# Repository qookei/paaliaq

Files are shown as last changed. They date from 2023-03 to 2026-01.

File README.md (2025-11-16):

# Paaliaq

Paaliaq is a WDC W65C816-based single board computer and the
accompanying software, with support for e.g. modern memory management
features, and kernel/user priviledge separation.

The project is currently in early stages of development, with most of
the current work focusing on the chipset implemntation. Proper
documentation TBD.

## Specifications

Using the iCESugar-pro SoM with the following specifications as the
base FPGA board:

 - Lattice ECP5 LFE5U-25F FPGA
 - 32MiB of SDR SDRAM
 - 32MiB SPI flash (holding the bitstream, with free space after it)
 - SD card slot
 - RGB led

The project is currently using a soft-core 65C816 implementation, with
future plans for a custom PCB holding an actual 65C816 chip, a SODIMM
slot for the FPGA SoM and breaking out various IO interfaces (HDMI,
UARTs, GPIO, etc).

## How?

Supporting the features mentioned above is made possible due to the
inclusion of the `ABORTB` signal on the 65C816 CPU, which allows the
currently executing instruction to be aborted, preventing register
changes and memory reads/writes, and allowing the instruction to
potentially be retried after returning from the handler.

To facilitate this, the FPGA contains not only the memory controller
and various peripherals, but also a page-based memory management unit,
which performs address translation and permission checks, signaling
errors to the CPU via the aforementioned abort signal.

## Directory structure and building

Each of the following subdirectories has instructions on how to build
it's contents:

 - `rtl` - The source code for the FPGA implementation of the chipset.
 - `toolchain` - The source code for the toolchain (assembler, etc).

## License

This project is licensed under the GNU General Public License, either
version 3, or (at your opinion) any later version.

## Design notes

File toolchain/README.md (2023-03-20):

# Paaliaq toolchain

This directory contains the sources for the toolchain designed for use
with the system.

The toolchain is written in Scheme and uses [GNU Guile](https://www.gnu.org/software/guile/)
as the Scheme implementation.

In contrast to regular assemblers, this assembler can be thought of more
as a set of functions and libraries that provide an assembly-looking DSL,
with the full power of Scheme for implementing assembler macros and such.

The main component of the assembler is the `paaliaq-as` script, which
contains the core functionality (translating instruction mnemonics into
bytes and such), and handles processing the command-line arguments and
loading the user-specified sources.

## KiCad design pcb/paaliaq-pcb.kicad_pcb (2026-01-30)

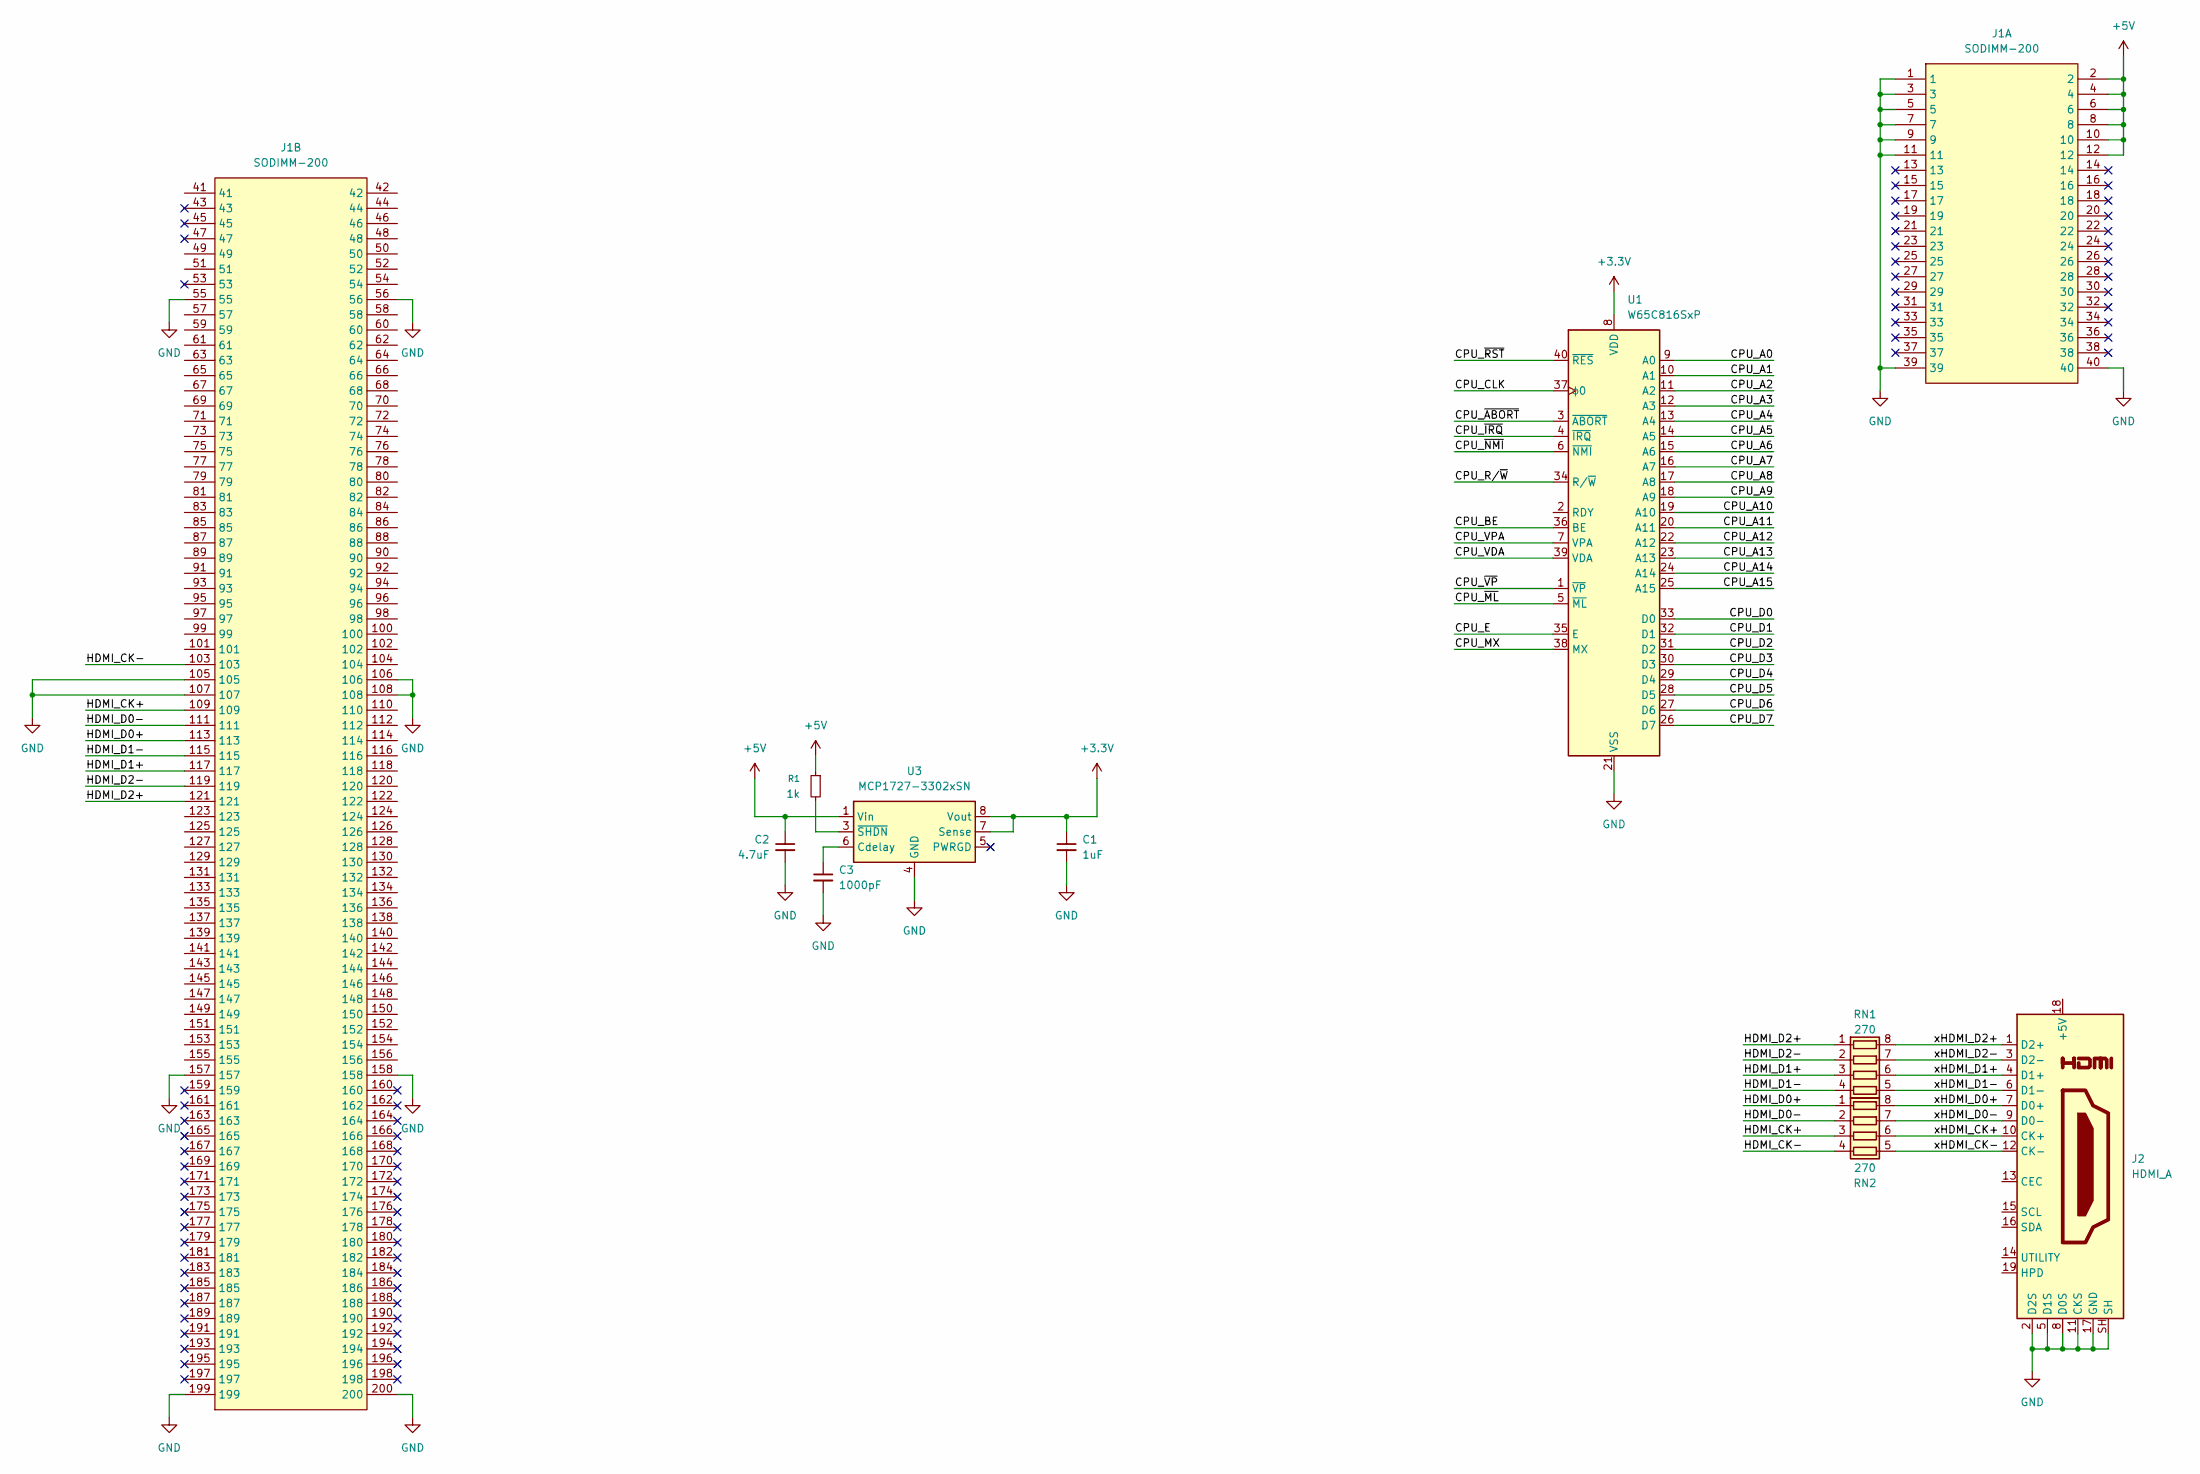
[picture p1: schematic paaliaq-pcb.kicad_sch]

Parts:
C1: 1uF; C_0805_2012Metric_Pad1.18x1.45mm_HandSolder
C2: 4.7uF; C_0805_2012Metric_Pad1.18x1.45mm_HandSolder
C3: 1000pF; C_0805_2012Metric_Pad1.18x1.45mm_HandSolder
J1: SODIMM-200; TE_1473005-1_2x100_P0.6mm_Horizontal
J2: HDMI_A; HDMI_A_Amphenol_10029449-x01xLF_Horizontal
R1: 1k; R_0805_2012Metric_Pad1.20x1.40mm_HandSolder
RN1, RN2: 270; R_Array_Convex_4x1206
U1: W65C816SxP; DIP-40_W15.24mm_Socket
U3: MCP1727-3302xSN; SOIC-8_3.9x4.9mm_P1.27mm

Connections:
+3.3V: C1.1, U1.8 (VDD), U3.7 (Sense), U3.8 (Vout)
+5V: C2.1, J1.2, J1.4, J1.6, J1.8, J1.10, J1.12, R1.1, U3.1 (Vin), U3.2 (Vin)
/CPU_A0: U1.9 (A0)
/CPU_A1: U1.10 (A1)
/CPU_A2: U1.11 (A2)
/CPU_A3: U1.12 (A3)
/CPU_A4: U1.13 (A4)
/CPU_A5: U1.14 (A5)
/CPU_A6: U1.15 (A6)
/CPU_A7: U1.16 (A7)
/CPU_A8: U1.17 (A8)
/CPU_A9: U1.18 (A9)
/CPU_A10: U1.19 (A10)
/CPU_A11: U1.20 (A11)
/CPU_A12: U1.22 (A12)
/CPU_A13: U1.23 (A13)
/CPU_A14: U1.24 (A14)
/CPU_A15: U1.25 (A15)
/CPU_BE: U1.36 (BE)
/CPU_CLK: U1.37 (ϕ0)
/CPU_D0: U1.33 (D0)
/CPU_D1: U1.32 (D1)
/CPU_D2: U1.31 (D2)
/CPU_D3: U1.30 (D3)
/CPU_D4: U1.29 (D4)
/CPU_D5: U1.28 (D5)
/CPU_D6: U1.27 (D6)
/CPU_D7: U1.26 (D7)
/CPU_E: U1.35 (E)
/CPU_MX: U1.38 (MX)
/CPU_R/~W: U1.34 (R/~W)
/CPU_VDA: U1.39 (VDA)
/CPU_VPA: U1.7 (VPA)
/CPU_~ABORT: U1.3 (~ABORT)
/CPU_~IRQ: U1.4 (~IRQ)
/CPU_~ML: U1.5 (~ML)
/CPU_~NMI: U1.6 (~NMI)
/CPU_~RST: U1.40 (~RES)
/CPU_~VP: U1.1 (~VP)
/HDMI_CK+: J1.109, RN2.3 (R3.1)
/HDMI_CK-: J1.103, RN2.4 (R4.1)
/HDMI_D0+: J1.113, RN2.1 (R1.1)
/HDMI_D0-: J1.111, RN2.2 (R2.1)
/HDMI_D1+: J1.117, RN1.3 (R3.1)
/HDMI_D1-: J1.115, RN1.4 (R4.1)
/HDMI_D2+: J1.121, RN1.1 (R1.1)
/HDMI_D2-: J1.119, RN1.2 (R2.1)
/xHDMI_CK+: J2.10 (CK+), RN2.6 (R3.2)
/xHDMI_CK-: J2.12 (CK-), RN2.5 (R4.2)
/xHDMI_D0+: J2.7 (D0+), RN2.8 (R1.2)
/xHDMI_D0-: J2.9 (D0-), RN2.7 (R2.2)
/xHDMI_D1+: J2.4 (D1+), RN1.6 (R3.2)
/xHDMI_D1-: J2.6 (D1-), RN1.5 (R4.2)
/xHDMI_D2+: J2.1 (D2+), RN1.8 (R1.2)
/xHDMI_D2-: J2.3 (D2-), RN1.7 (R2.2)
GND: C1.2, C2.2, C3.2, J1.1, J1.3, J1.5, J1.7, J1.9, J1.11, J1.39, J1.40, J1.55, J1.56, J1.105, J1.106, J1.107, J1.108, J1.157, J1.158, J1.199, J1.200, J2.2 (D2S), J2.5 (D1S), J2.8 (D0S), J2.11 (CKS), J2.17 (GND), J2.SH, U1.21 (VSS), U3.4 (GND)
unnamed: C3.1, U3.6 (Cdelay)
unnamed: R1.2, U3.3 (~SHDN)

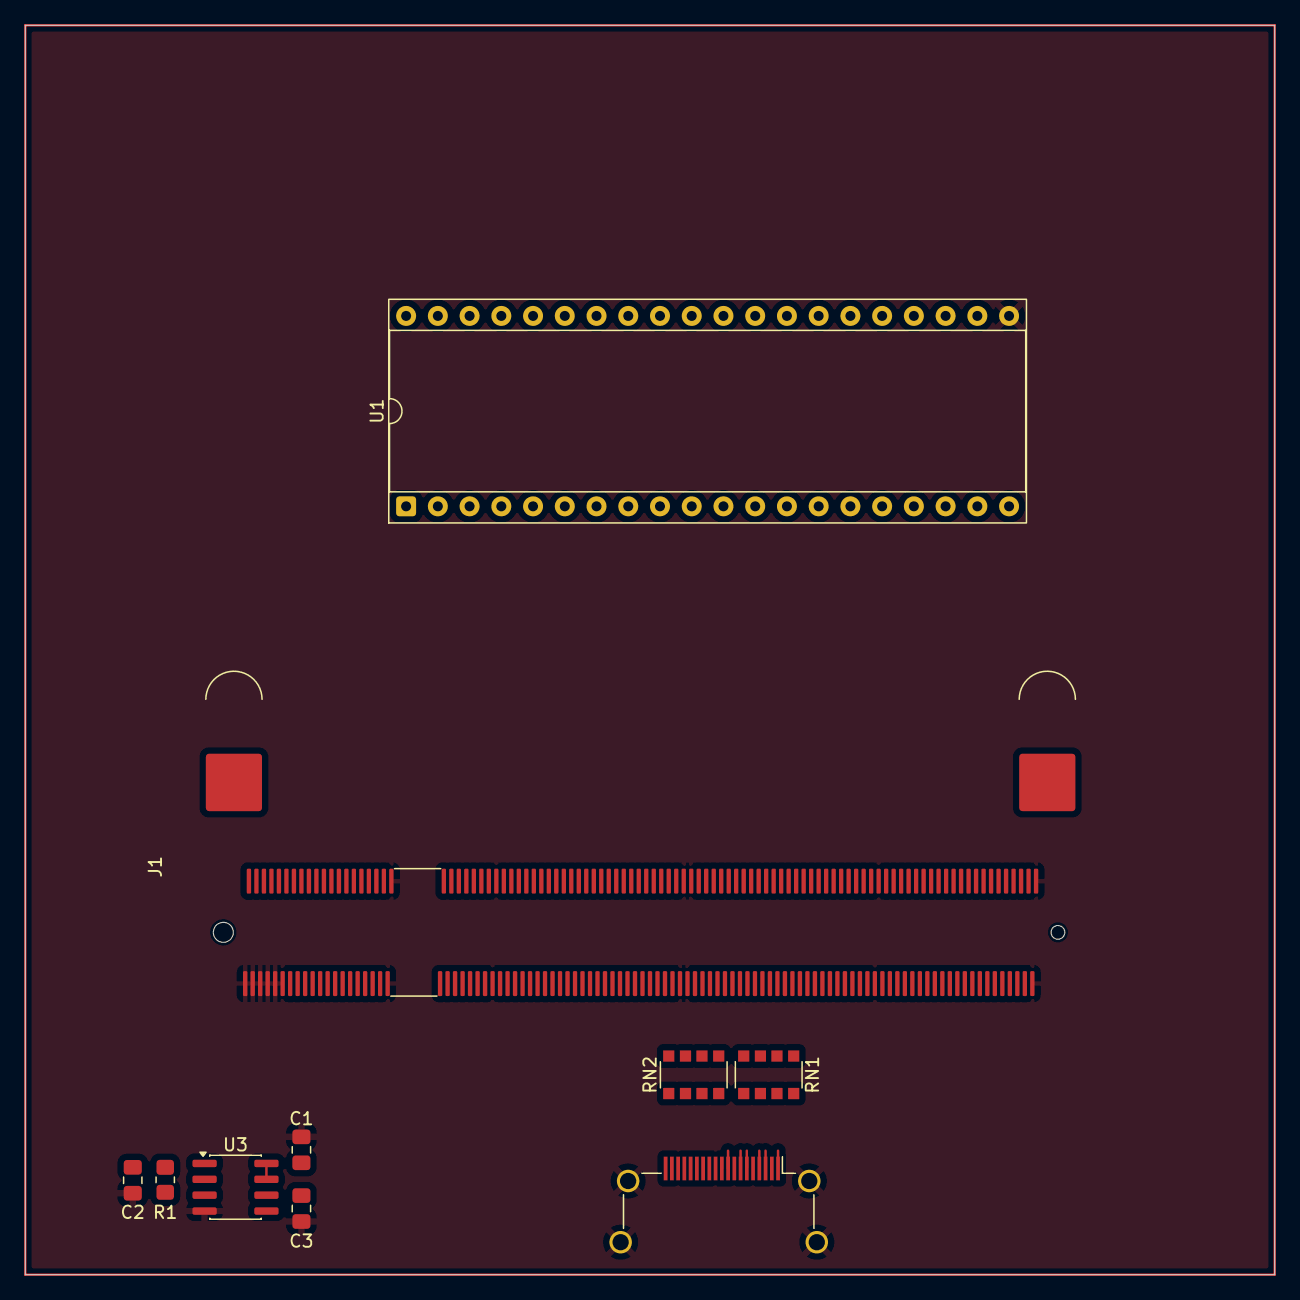
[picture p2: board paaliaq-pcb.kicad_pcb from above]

Board: 2 copper layers, 100.0 x 100.0 mm, 10 parts (0 on the bottom side), 21 nets.

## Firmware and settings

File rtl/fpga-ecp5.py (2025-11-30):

import argparse, math

from amaranth import *
from amaranth.lib import wiring, io
from amaranth.build import *
from amaranth.vendor import LatticeECP5Platform
from amaranth_boards.resources import *

from soc import SoC
from sdram import SDRAMConnector
from cpu import W65C816Connector, P65C816SoftCore

from pll import ECP5PLL


class TopLevel(Elaboratable):
    def __init__(self, *, target_clk=75e6, external_cpu=False, boot_rom_path):
        super().__init__()
        self._target_clk = target_clk
        self._external_cpu = external_cpu
        self._boot_rom_path = boot_rom_path

    def elaborate(self, platform):
        m = Module()

        m.domains.clk25 = cd_clk25 = ClockDomain(platform.default_clk)
        m.submodules.clk = clk = io.Buffer("i", platform.request(platform.default_clk, dir="-"))
        m.d.comb += ClockSignal(platform.default_clk).eq(clk.i)

        clk_freq = platform.default_clk_frequency

        m.domains.sync = cd_sync = ClockDomain("sync")
        m.domains.sdram = cd_sdram = ClockDomain("sdram")

        m.submodules.pll = pll = ECP5PLL()
        pll.add_input(clk=clk.i, freq=clk_freq)
        pll.add_primary_output(freq=self._target_clk)
        pll.add_secondary_output(domain="sdram", freq=self._target_clk, phase=180)

        m.submodules.soc = soc = SoC(target_clk=self._target_clk, boot_rom_path=self._boot_rom_path)

        uart = platform.request("uart", dir="-")
        m.submodules.uart_tx = uart_tx = io.Buffer("o", uart.tx)
        m.submodules.uart_rx = uart_rx = io.Buffer("i", uart.rx)

        m.d.comb += [
            uart_tx.o.eq(soc.tx),
            soc.rx.eq(uart_rx.i),
        ]

        led = platform.request("rgb_led", dir="-")
        m.submodules.led_r = led_r = io.FFBuffer("o", led.r, o_domain="clk25")
        m.submodules.led_g = led_g = io.FFBuffer("o", led.g, o_domain="clk25")
        m.submodules.led_b = led_b = io.FFBuffer("o", led.b, o_domain="clk25")

        period_ctr = Signal(8)
        duty_ctr = Signal(8)
        duty_dir = Signal()
        led_sel = Signal(3, init=1)

        timing = Signal(range(125000))
        m.d.clk25 += timing.eq(timing + 1)

        with m.If(timing == 124999):
            m.d.clk25 += timing.eq(0)

            with m.If(duty_dir):
                with m.If(duty_ctr == 0):
                    m.d.clk25 += duty_dir.eq(~duty_dir)
                    m.d.clk25 += led_sel.eq(led_sel.rotate_left(1))
                with m.Else():
                    m.d.clk25 += duty_ctr.eq(duty_ctr - 1)
            with m.Else():
                with m.If(duty_ctr == 255):
                    m.d.clk25 += duty_dir.eq(~duty_dir)
                with m.Else():
                    m.d.clk25 += duty_ctr.eq(duty_ctr + 1)

        m.d.clk25 += period_ctr.eq(period_ctr + 1)

        m.d.comb += led_r.o.eq((duty_ctr >= period_ctr) & (led_sel == 0b001))
        m.d.comb += led_g.o.eq((duty_ctr >= period_ctr) & (led_sel == 0b010))
        m.d.comb += led_b.o.eq((duty_ctr >= period_ctr) & (led_sel == 0b100))

        m.submodules.sdram = sdram = SDRAMConnector()
        wiring.connect(m, sdram.sdram, soc.sdram)

        m.submodules.cpu = cpu = W65C816Connector() if self._external_cpu else P65C816SoftCore()
        wiring.connect(m, cpu.iface, soc.cpu)

        return m


def W65C816Resource(*args, clk, rst, addr, data, rwb, vda, vpa, vpb,
                    irq, nmi, abort, conn=None, attrs=None):
    io = []

    io.append(Subsignal('clk', Pins(clk, dir='o', conn=conn, assert_width=1)))
    io.append(Subsignal('rst', Pins(rst, dir='o', conn=conn, assert_width=1)))

    io.append(Subsignal('addr', Pins(addr, dir='i', conn=conn, assert_width=16)))
    io.append(Subsignal('data', Pins(data, dir='io', conn=conn, assert_width=8)))

    io.append(Subsignal('rwb', Pins(rwb, dir='i', conn=conn, assert_width=1)))
    io.append(Subsignal('vda', Pins(vda, dir='i', conn=conn, assert_width=1)))
    io.append(Subsignal('vpa', Pins(vpa, dir='i', conn=conn, assert_width=1)))
    io.append(Subsignal('vpb', Pins(vpb, dir='i', conn=conn, assert_width=1)))

    io.append(Subsignal('irq',   Pins(irq,   dir='o', conn=conn, assert_width=1)))
    io.append(Subsignal('nmi',   Pins(nmi,   dir='o', conn=conn, assert_width=1)))
    io.append(Subsignal('abort', Pins(abort, dir='o', conn=conn, assert_width=1)))

    if attrs is not None:
        io.append(attrs)
    return Resource.family(*args, default_name='w65c816', ios=io)


def HDMIResource(*args, clk_p, clk_n, data_p, data_n, conn=None, attrs=None):
    io = []

    io.append(Subsignal('clk_p', Pins(clk_p, dir='o', conn=conn, assert_width=1)))
    io.append(Subsignal('clk_n', Pins(clk_n, dir='o', invert=True, conn=conn, assert_width=1)))
    io.append(Subsignal('data_p', Pins(data_p, dir='o', conn=conn, assert_width=3)))
    io.append(Subsignal('data_n', Pins(data_n, dir='o', invert=True, conn=conn, assert_width=3)))

    if attrs is not None:
        io.append(attrs)
    return Resource.family(*args, default_name='hdmi', ios=io)

class PaaliaqPlatform(LatticeECP5Platform):
    device      = "LFE5U-25F"
    package     = "BG256"
    speed       = "6"
    default_clk = "clk25"


    def __init__(self, *, allow_timing_fail=False):
        super().__init__()
        self._allow_timing_fail = allow_timing_fail


    resources = [
        Resource("clk25", 0, Pins("P6", dir="i"), Clock(25e6), Attrs(IO_TYPE="LVCMOS33")),

        RGBLEDResource(
            0,
            r="B11", g="A11", b="A12",
            attrs=Attrs(IO_TYPE="LVCMOS33", DRIVE="4")
        ),

        SDRAMResource(0,
            clk="R15", cke="L16", we_n="A15", cas_n="G16", ras_n="B16", dqm="C16 T15",
            ba="G15 B14", a="H15 B13 B12 J16 J15 R12 K16 R13 T13 K15 A13 R14 T14",
            dq="F16 E15 F15 D14 E16 C15 D16 B15 R16 P16 P15 N16 N14 M16 M15 L15",
            attrs=Attrs(PULLMODE="NONE", DRIVE="4", SLEWRATE="FAST", IO_TYPE="LVCMOS33")
        ),

        UARTResource(0, rx="A9", tx="B9"),

        HDMIResource(
            0,
            clk_p="E2", clk_n="D3",
            data_p="G1 J1 L1",
            data_n="F1 H2 K2",
            attrs=Attrs(DRIVE="4", IO_TYPE="LVCMOS33"),
        ),

        # XXX(qookie): This is not the final pin assignment. I haven't
        # designed the PCB with the CPU yet, I just want to see the
        # fMAX when using an external CPU.
        #W65C816Resource(
        #    0,
        #    clk="C4", rst="D4",
        #    addr="E4 D3 F5 E3 F1 F2 G2 G1 H2 H3 B1 C2 C1 D1 E2 E1",
        #    data="P5 R3 P2 R2 T2 N6 N14 R12",
        #    rwb="R14", vda="T14", vpa="P12", vpb="P14",
        #    irq="R15", nmi="T15", abort="P13",
        #    attrs=Attrs(PULLMODE="NONE", DRIVE="4", SLEWRATE="FAST", IO_TYPE="LVCMOS33")
        #)
    ]

    connectors = []

    def toolchain_prepare(self, fragment, name, **kwargs):
        overrides = dict(ecppack_opts="--compress")
        if self._allow_timing_fail:
            overrides['nextpnr_opts'] = '--timing-allow-fail'
        overrides.update(kwargs)
        return super().toolchain_prepare(fragment, name, **overrides)


if __name__ == '__main__':
    parser = argparse.ArgumentParser()
    parser.add_argument('--external-cpu', action='store_true')
    parser.add_argument('--allow-timing-fail', action='store_true')
    parser.add_argument('--target-clk', type=int, default=75)
    parser.add_argument("--boot-rom", type=str, default="../build/boot0.bin")

    args = parser.parse_args()
    platform = PaaliaqPlatform(allow_timing_fail=args.allow_timing_fail)
    with open("external/P65C816.v", "r") as f:
        platform.add_file("P65C816.v", f)
    platform.build(TopLevel(
        external_cpu=args.external_cpu,
        target_clk=args.target_clk * 1e6,
        boot_rom_path=args.boot_rom,
    ))

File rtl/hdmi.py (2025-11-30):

from amaranth import *
from amaranth.lib import wiring, io
from amaranth.lib.wiring import In, Out

from dataclasses import dataclass, field


class TMDSEncoder(wiring.Component):
    active: In(1)
    data_in: In(8)
    c0: In(1)
    c1: In(1)

    data_out: Out(10)


    def elaborate(self, platform):
        m = Module()

        data_min = Signal(9)
        m.d.comb += data_min[0].eq(self.data_in[0])

        in_1_cnt = sum(self.data_in)

        with m.If((in_1_cnt > 4) | ((in_1_cnt == 4) & ~self.data_in[0])):
            m.d.comb += data_min[8].eq(0)
            for i in range(1, 8):
                m.d.comb += data_min[i].eq(~(self.data_in[i] ^ data_min[i - 1]))
        with m.Else():
            m.d.comb += data_min[8].eq(1)
            for i in range(1, 8):
                m.d.comb += data_min[i].eq(self.data_in[i] ^ data_min[i - 1])

        in_balance = in_1_cnt - 4
        total_balance = Signal(signed(4))

        out = Signal(10)

        with m.If((in_balance == 0) | (total_balance == 0)):
            with m.If(data_min[8]):
                m.d.comb += out.eq(Cat(data_min, 0))
                m.d.sync += total_balance.eq(total_balance + in_balance)
            with m.Else():
                m.d.comb += out.eq(Cat(~data_min[0:8], 0, 1))
                m.d.sync += total_balance.eq(total_balance - in_balance)
        with m.Else():
            with m.If(in_balance[3] == total_balance[3]):
                m.d.comb += out.eq(Cat(~data_min[0:8], data_min[8], 1))
                m.d.sync += total_balance.eq(total_balance + data_min[8] - in_balance)
            with m.Else():
                m.d.comb += out.eq(Cat(data_min, 0))
                m.d.sync += total_balance.eq(total_balance - (~data_min[8]) + in_balance)

        with m.If(self.active):
            m.d.sync += self.data_out.eq(out)
        with m.Else():
            m.d.sync += [
                total_balance.eq(0),
                self.data_out.eq(
                    Array([
                        0b0010101011,
                        0b0010101010,
                        0b1101010100,
                        0b1101010101,
                    ])[Cat(self.c1, self.c0)]
                ),
            ]

        return m


@dataclass
class VideoMode:
    width: int
    height: int
    pixel_clock: int

    h_front_porch: int
    h_back_porch: int
    h_sync: int
    h_total: int = field(init=False)
    h_active_start: int = field(init=False)
    h_active_end: int = field(init=False)
    h_sync_start: int = field(init=False)

    v_front_porch: int
    v_back_porch: int
    v_sync: int
    v_total: int = field(init=False)
    v_active_start: int = field(init=False)
    v_active_end: int = field(init=False)
    v_sync_start: int = field(init=False)


    def __post_init__(self):
        self.v_total = self.v_front_porch + self.height + self.v_back_porch + self.v_sync
        self.h_total = self.h_front_porch + self.width  + self.h_back_porch + self.h_sync

        self.v_active_start = self.v_back_porch
        self.v_active_end = self.v_back_porch + self.height
        self.v_sync_start = self.v_active_end + self.v_front_porch

        self.h_active_start = self.h_back_porch
        self.h_active_end = self.h_back_porch + self.width
        self.h_sync_start = self.h_active_end + self.h_front_porch


DMT_MODE_640x480_60Hz = VideoMode(
    width=640,
    height=480,
    pixel_clock=25000000,
    h_front_porch=16,
    h_back_porch=48,
    h_sync=96,
    v_front_porch=10,
    v_back_porch=33,
    v_sync=2,
)

DMT_MODE_800x600_60Hz = VideoMode(
    width=800,
    height=600,
    pixel_clock=40000000,
    h_front_porch=40,
    h_back_porch=88,
    h_sync=128,
    v_front_porch=1,
    v_back_porch=23,
    v_sync=4,
)

DMT_MODE_1024x768_60Hz = VideoMode(
    width=1024,
    height=768,
    pixel_clock=65000000,
    h_front_porch=24,
    h_back_porch=160,
    h_sync=136,
    v_front_porch=3,
    v_back_porch=29,
    v_sync=6,
)

CTA_MODE_1280x720_60Hz = VideoMode(
    width=1280,
    height=720,
    pixel_clock=75000000,
    h_front_porch=110,
    h_back_porch=220,
    h_sync=40,
    v_front_porch=5,
    v_back_porch=20,
    v_sync=5,
)

SMPTE_MODE_1920x1080_30Hz = VideoMode(
    width=1920,
    height=1080,
    pixel_clock=75000000,
    h_front_porch=88,
    h_back_porch=148,
    h_sync=44,
    v_front_porch=4,
    v_back_porch=36,
    v_sync=5,
)


class VideoSequencer(wiring.Component):
    h_sync: Out(1)
    v_sync: Out(1)
    active: Out(1)

    h_pos: Out(16)
    v_pos: Out(16)

    h_start: Out(1)
    v_start: Out(1)


    def __init__(self, mode, pipeline_depth=0):
        super().__init__()
        self.mode = mode
        self.pipeline_depth = pipeline_depth

    def elaborate(self, platform):
        m = Module()

        mode = self.mode

        if self.pipeline_depth > mode.h_active_start:
            raise ValueError("Requested pixel pipeline is too deep")

        h_pos = Signal(range(mode.h_total))
        v_pos = Signal(range(mode.v_total))

        h_active = (h_pos >= mode.h_active_start) & (h_pos < mode.h_active_end)
        v_active = (v_pos >= mode.v_active_start) & (v_pos < mode.v_active_end)

        m.d.sync += [
            self.h_sync.eq(h_pos >= mode.h_sync_start),
            self.h_sync.eq(v_pos >= mode.v_sync_start),
            self.active.eq(h_active & v_active),
        ]

        h_edge = h_pos == mode.h_total - 1
        v_edge = v_pos == mode.v_total - 1

        m.d.sync += h_pos.eq(h_pos + 1)
        with m.If(h_edge):
            m.d.sync += [
                h_pos.eq(0),
                v_pos.eq(Mux(v_edge, 0, v_pos + 1)),
            ]

        pipeline_h_active_start = mode.h_active_start - self.pipeline_depth
        pipeline_h_active_end = mode.h_active_end - self.pipeline_depth

        pipeline_h_active = (h_pos >= pipeline_h_active_start) & (h_pos < pipeline_h_active_end)
        pipeline_active = pipeline_h_active & v_active

        m.d.sync += [
            self.h_start.eq(h_pos == pipeline_h_active_start - 1),
            self.v_start.eq(h_edge & v_edge),
            self.h_pos.eq(Mux(pipeline_active, h_pos - pipeline_h_active_start, 0)),
            self.v_pos.eq(Mux(pipeline_active, v_pos - mode.v_active_start, 0)),
        ]

        return m
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

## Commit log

2023-03-20 toolchain: Add a Scheme-based 65c816 assembler
    This is more of a library + launcher for Scheme programs that generate
    code for the 65c816, but it's primary use is as an assembler.
2023-03-23 toolchain: as: Replace custom partial-apply with SRFI 26 cut
2023-10-28 toolchain: Get rid of local labels
    Instead, labels (and the respective relocations) are now processed
    before the object is returned from `assemble'.
2023-10-31 toolchain: Add module with raw ELF file definitions
    This marks the beginning of our transition to use regular ELF files as
    outputs from the assembler and linker.
    In addition to the assembler and linker we'll need to implement an
    objcopy (I'm quite sure the GNU binutils one will bail out if it doesn't
    know about the architecture). objcopy will be necessary for at least
    producing the boot ROM image to be embedded into the chipse.
    This module currently goes unused, adding it just in case...
2024-02-27 toolchain: Rewrite assembler
    This is still not hooked up to anything, and I still plan on changing
    the symbols for the various addressing modes.
2024-02-27 toolchain: Add module with code to emit ELF files
    Currently only has code to emit object files.
    I think the section procedures (%.text, etc.) ought to be in their own
    module, I think the assembler will use them as well.
    The string interning procedure also seems useful, and should probably
    go into some generic utility module.
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2024-02-27 toolchain: Add core assembler module
    The module that provides more of the DSL (for declaring sections and
    procedures themselves is still to be done).
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2024-02-29 toolchain: Add helper assemble procedure
    This procedure wraps around assemble-many, automatically creating a
    default state, and discarding the resulting output state.
2024-03-01 toolchain: Add procedure for generating data tables
    This procedure reuses the assembler internals for handling symbol
    references.
2024-03-01 toolchain: Add module providing assembler DSL macros and procedures
    This code is still a bit ugly (the repetition around wrapping the body
    in a symbol is quite ugly for example). Perhaps symbols should be
    created like so: `(sym foo (.proc ...))' etc.
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2024-03-01 toolchain: Turn paaliaq-as into a shell script
    paaliaq-as is now a simple shell script that figures out where it is,
    and evaluates the actual assembler script with the proper arguments.
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2024-03-01 toolchain: Support sub-lists of instructions in assembler DSL
    This allows for regular unquote to be used instead of
    unquote-splicing, reducing the visual noise a bit (,x vs ,@x).
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2025-01-30 rtl-new: Begin refactoring and porting to an ECP5 platform
    Port to amaranth.lib.wiring for nice helpers for wiring stuff up, add
    support for using a 65C816 soft-core for now (until I actually buy a
    real chip and hook it up), add an UART transmitter, and make the code
    synthesize on an Lattice ECP5 board (Colorlight 5A-75B V8.2).
2025-01-31 rtl-new: Fix wishbone bridge write cycles
    Without setting SEL_O writes do nothing (even if the bus has
    data_width == granularity).
    [cpu.py]
2025-01-31 rtl-new: Rework how the CPU Wishbone bridge state machine works
    Each state that uses the counter has the counter start at 0, instead
    of the counter counting up from the point the clock went low.
    [cpu.py]
2025-01-31 rtl-new: Improve the CPU bus trace
    This should probably be cleaned up and moved to a separate
    module (perhaps integrated into the CPU state machine so we actually
    sample everything at the right time).
2025-01-31 rtl-new: Add separate states for managing CPU reset
    [cpu.py]
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2025-02-04 rtl-new: Add entry point to generate a Verilog file for simulation
    One small hack: at the low clock speed we pretend to have (1.7MHz;
    N.B. ~3x higher than the speed the verilated model runs at), the CPU
    is clocking faster than the debug probe can stream the data out,
    leading to TX FIFO overflows in the debug probe. Temporarily solved by
    adding 1 clock to the CPU timings.
    [cpu.py, sim.py, top.py]
2025-02-04 rtl-new: Lower the fake platform clock speed
    This speeds up UART TX in simulation since the multiplier is how many
    clocks each bit ends up taking.
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2025-02-05 rtl-new: Reorganize UART status register
    This allows the BIT instruction to be used to quickly check the flags.
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2025-02-06 toolchain: Use guile-3.0 by default
    Some time ago the Guile executable name changed from just guile to
    guile-3.0 on Gentoo (due to slot support for Guile).
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2025-02-09 rtl-new: Get rid of extra UART FSM states between stop and idle
2025-02-10 rtl-new: Fix MMU page table writes writing to a wrong address
    [mmu.py]
2025-02-10 rtl-new: Temporarily wire abort symbol to NMI input
    The P65C816 soft-core does not implement ABORT apart from making it
    wake the CPU up from a WAI instruction, so until a real W65C816 is
    used, this will have to do.
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2025-02-17 rtl-new: Add a simple SDRAM controller and wire it up
    The controller as it stands is pretty unoptimized, and wastes 3/4ths
    of the 8MiB of SDRAM on-board.
    Some optimizations include: keeping rows active between accesses,
    adding a cache and doing larger bursts for reads and writes (which
    would also help solve the wasted space problem).
    The RAM is partially wasted because the board I'm using has DQM{0..3}
    all wired low, so the FPGA can't select individual bytes to write.
    Currently this is worked around by using whole 32-bit words to store
    individual byte.
    [fpga-ecp5.py, sdram.py, sim.py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]
2025-02-17 rtl-new: Make full use of SDRAM capacity
    Instead of wasting 3/4ths of every word, allow individual access to
    all bytes within the word. For writes, this means we perform a read
    command before, because we can't mask off bytes we don't want to
    write. This does mean writes are a bit slower now, but it's only by 3
    clock cycles (one to issue the read command, two for CAS latency).
    [sdram.py]
2025-02-19 rtl: Remove obsolete and unused code
    The new RTL implemented in Amaranth contains the same
    functionality (and more!) than the old SpinalHDL implementation, and
    is actually working on a real FPGA board.
2025-02-19 rtl-new: Move SDRAM base address to 0x800000
    Bus transactions targetting the SDRAM seemed to get stuck at (or
    around?) address 0x800000 with the base address at 0x200000.
    I intended for this to be the base address for the SDRAM either way,
    not sure why I even put it at 0x200000 to begin with...
    [top.py]
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2025-02-19 rtl-new: Add W65C816 resource to the platform with mock pinout
    As the comment above the resource notes, I haven't done any actual
    layout yet so those pin assignments are random (approximately just
    going through all the HUB75 connector {R,G,B}{0,1} pins in order on
    the board).
2025-02-19 rtl-new: Replace handwritten UART PHY with one from amaranth-stdio
    Also add missing FFSynchronizer on the RX pin (AFAICT with this
    missing, the reciever sometimes gets stuck at 75MHz).
    [top.py, uart.py]
2025-03-02 rtl: Keep SDRAM rows active for as long as possible
    Within each bank we can have one row active at a time, and we don't
    need to precharge it between reads/writes. The only times we need to
    issue a precharge command is when switching rows, and during
    refresh (which precharges rows on all banks).
    This has a noticeable improvement on the memory access times.
    [sdram.py]
2025-05-11 rtl: Make target frequency configurable
    Also add argument to ignore timing analysis failures. :^)
    [fpga-ecp5.py]
2025-05-11 rtl: Fix simulation top-level module
    [sim.py]
2025-05-18 rtl: Begin work on an JTAG debug interface
    This commit adds an implementation of the core JTAG interface based on
    the ECP5 JTAGG primitive. Actual debug interface is to be done,
    currently all that is done is just piping all incoming data into the
    output FIFO.
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2025-05-18 rtl: Replace >= with == in CPU interface logic
    Not sure if this makes a huge difference, but the change makes sense
    in my head. :^)
    [cpu.py]
2025-05-18 rtl: Add missing import to jtag.py
    [jtag.py]
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2025-05-18 scripts: Add scripts for remote debugging with OpenOCD
    [ftdi-ft2232-cjmcu.cfg]
2025-05-24 rtl: Get rid of old debug probe and clean up
    The old debug probe that fed off of the CPU's signals directly was
    broken for a while now (due to no clock speed limiting in the CPU
    bridge), and has now been superseded by the new registers accessible
    over JTAG added in the previous commit.
    [fpga-ecp5.py, sim.py, soc.py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]
2025-05-25 rtl: Register debug enable state for the current CPU cycle
    If debugging is disabled before the final read/write completes, the
    CPU cycle would never actually complete.
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2025-06-27 scripts: Add script to format the current git revision
    Simple wrapper around `git describe` with error handling (in case .git
    is missing or something).
2025-07-10 rtl: Remove obsolete comment
    ABC9 is no longer disabled since the previous commit.
    [fpga-ecp5.py]
2025-07-14 rtl,scripts: Port to Colorlight i5 board
    This board doesn't have any I/O buffers on the pins, and the dev board
    has an HDMI connector.
    [cmsis-dap.cfg]
2025-07-14 rtl: Add missing PLL parameters
    The values of these parameters is just what ecppll writes out, and it
    seems to be constant. No idea what they mean, and the Lattice IP docs
    don't say either.
    [pll.py]
2025-07-15 rtl: Replace implicit platform.request IO buffers with explicit ones
    All uses of platform.request() without dir="-" are deprecated.
    [cpu.py, fpga-ecp5.py, sdram.py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]
2025-07-20 rtl: Add a 128x48 color text framebuffer
    This provides an interface similar to VGA text mode, with two bytes
    per character: one for the CP 437 code, and one for the foreground and
    background colors. Also implements a text cursor (although it's not
    yet wired up to registers to move it around).
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2025-11-16 rtl: Don't use differencial pair I/Os for HDMI
    This is needed for the iCESugar-pro w/ dev-board, which has HDMI
    routed to pins that don't form differencial pairs...
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2025-11-30 rtl: Add extra stage in pixel pipeline
    This shortens the critical path in the pixel clock domain and fixes
    the timing violation.
    [video.py]
2025-11-30 rtl: Make the PLLs map correctly in Lattice Diamond
    As noted in the comment, the phase computation seems wrong still, but
    other than that, they get mapped correctly (although the rest of the
    design doesn't work).
    [pll.py]
2025-11-30 rtl: Fix PLL phase parameter computation
    Now any arbitrary phase is supported, and the parameters should match
    what's produced by vendor tools.
    [pll.py]
2025-11-30 rtl: Use invert=True on HDMI pins instead of inverting manually
    Has better timing in addition to being cleaner, although I think the
    timings would be best to use proper differential pair IOs.
    [fpga-ecp5.py, hdmi.py]
2025-11-30 wip pcb
    [paaliaq-pcb.kicad_pcb, paaliaq-pcb.kicad_sch]
2025-11-30 wip dvi phy
    [paaliaq-pcb.kicad_pcb, paaliaq-pcb.kicad_sch]
2026-01-30 wip use resistor arrays and swap pairs and +/-
    [paaliaq-pcb.kicad_pcb, paaliaq-pcb.kicad_sch]
